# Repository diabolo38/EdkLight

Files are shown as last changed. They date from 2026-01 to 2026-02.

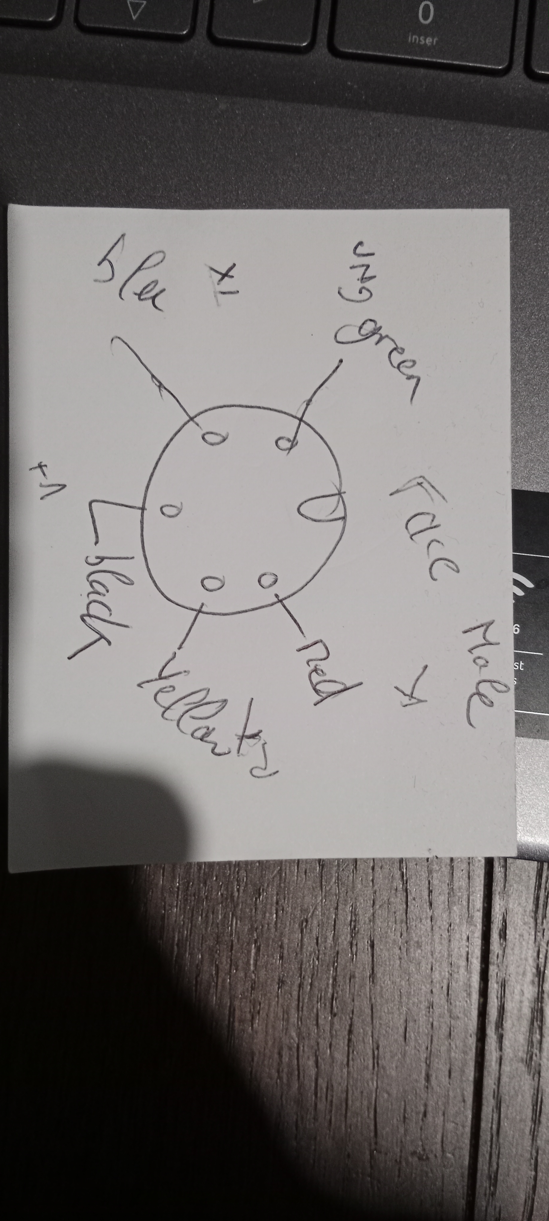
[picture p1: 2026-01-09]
doc/IMG_20260105_194908.jpg

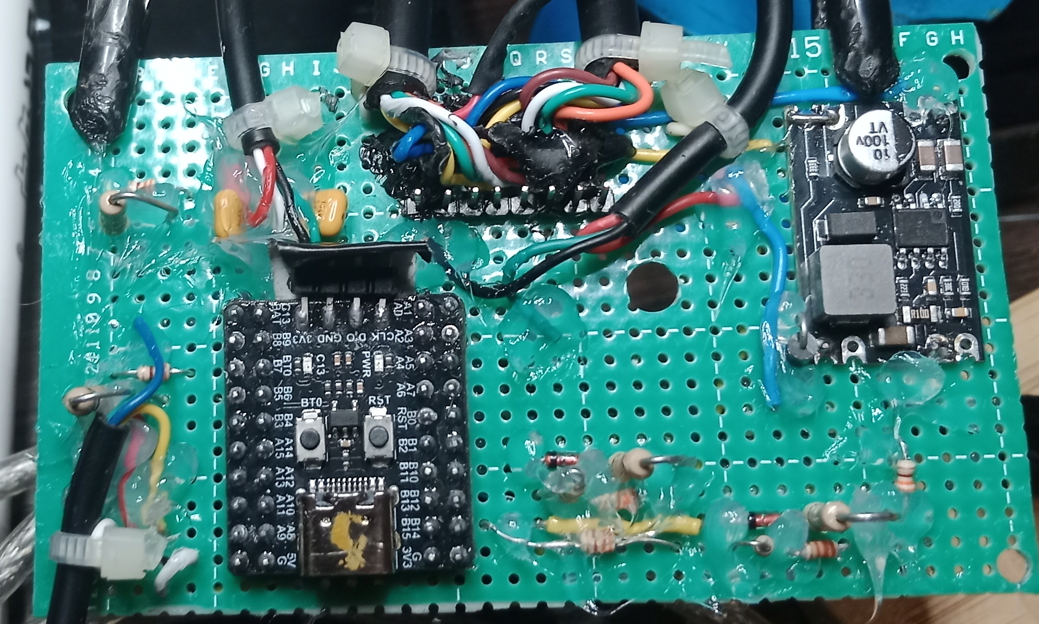
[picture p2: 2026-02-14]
doc/top.jpg

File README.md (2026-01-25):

Aim is to Drive my ebike light using the edk display light control via "+" key that is sent to motor via uart. 
optionaly brake light can be added  if conecting in at the higo 8 1 to 4 side.

An small mcu board stm32f103c6t6/c8t6  snif the edk-101  uart  and will enable power to light via  gpio base on control motor info snifed  
see https://github.com/hurzhurz/tsdz2/blob/master/serial-communication.md#motor-status-flags 

Hardware
---------
- Julet/Higo M8 5 pin Y spliter (light only) or Higo 8 extension for brake addition,  
- Julet 5 pin connector with 30cm wire take care that wires color don't seam to folow any standard (try conection and probe before to plug)
- 5V  step down  regulator with high enougth input voltage (54V + for 500W 48V TDS2B ) to feed 5V power from 48V bat line 
- MosFet  to drive  light pwoer (any mos capable to drive 500mA to 1A with  VDS max > 54V  ) 
- few discrete (zener, resistor)

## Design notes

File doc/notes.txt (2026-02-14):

ressource 
==========
wireless controler project for tsdz2 https://opensourceebike.github.io/easy_diy_display_ebike_display/tsdz2_wireless/ebike_wireless_controller.html 
schematic , cable pinout etc ....

connector 
========
Motor 4 to 1 source 
-------------------
higo 8 Pin (numbering from /ebike_wireless_controller) RX TX in motor sense 

    Brown/TX  8         2  Blue/Vbat
 Org/throt  7   1(GND)    3 Red/Vin(key)
Green/Brake   6         4 Yellow/RX
		           5 White/5V
		  color /pinout to be verified    GNB=black 
		  
 Check on mine (female view )
 1 black   GNB black ok
 2 blue    VBat
 3 red     Vin
 4 yellow  Rx  ok
 5 white   5V  ok
 6 Green   breake 
 7 Orang   Throt ok
 8 brown   Tx    ok
  all seamed ok as per number color but maping on function isn't ok 
		  
 functionaly it's not inline mine is 
 1 Gnd                            
 2 ? throt  analog 0 to 3.5V                             
 3 ? 4.3V  ? 5V 
 4 Rx 
 5 brake 
 6 TX  
 7 orange Vin                          
 8 brown VBat                                                         

Lcd/Motor 1 to 4 
--------
 Higo/Julet 5 pin M8 female , confirmed color as per my connector cable 
             (top Notch)
                   U     
  Gnd/Green     +    +  Key on /Red
Tx(RxLCD)/Blue  +    +  Rx(Tx lcd)/ Yellow
                  +
                 V+/Black (Bottom centered pin)

Ligth
------
front

https://fr.aliexpress.com/item/1005007666998243.html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

common ebike 36-80V led lamp with big front len
Max Powzer ~2.5W (50mA @ 54V)
 
3 lignes 
  rouge: ligne de corne / horn
  vert: ligne de lumière/ light
  noir: ligne commune  GND 
  
  Higo 3 pin cable extender female view front 
   
     Green  O   U    O Red  
          
                O Black

Rear 36/48V brake(flashing)+tail light 
   Red    ligh +
   black  ligh -
   
   Green Brake -
   Yellow Brake +

Higo 4 same color as light but black=blue 

 Red =>  lighjt + Vbat 
 black/blue = light -  on bot mos
 Green = brk - on bt mos 
 Yellow =brk + vbat
 
  female front view 
rouge L+   x  u  x green Brk - 
Yellow B+  x     x  Blue Light -

dual push buttton 
-------------------
Yellow 2x light (moded from auto locking to non locking) 
Blue  2x horn 

higo 4 
Red+black : light
white+green : horn 

  female front view 
  white  x  u  x Black
  Green  x     x  Red          
           bot 
mcu
=====
For dev proto the stm32f103 black pill low cost c6 or 8 (10K/20K sram)  
 https://stm32world.com/wiki/Black_Pill easier to wire 
 https://stm32-base.org/boards/STM32F103C8T6-Black-Pill.html
 https://hobbycomponents.com/st-micro-electronics/960-stm32f103-black-pill-development-board
The mini f103 10x2 he10 x2 more compact pcb aprox 2.54 x 2.54 cm vs 2.4 x 5.8 cm

Timers
-------- 
 # RX x1 x2 ?  idlle eof  time out  if to snif 2 Rx/Tx lcd/motor  => easy to avoid use last rx tick time in iddle loop to find eof
 # Rear Light PWM brake/full => this may not work if light has it's own dc/dc+ big enough cap unless pwm period quite low ( aka 100Hz range)
 # (opt? )  Rear blink time 
   
/!\ f103 has only 3 timer  + rtc => 4 h/w time source only out of 3 pwm capbale only 

UI
===

Brake : avoid keeping on/blink  , when keep pressed for too long and no move (aka press on red ligh)
when brake is on 
	if have speed or brake state chg : reset "keepOnDelay" ,  BrakeOverhide false
	else (no speed and no chg ) keepOnDelay elapsed check and set BrakeOverhide 

Light 
keep short to medium time presse for light on/off  
  if ligh presse => ligh on 
      after long press delay => setting mode 
   if ligh release before medium time => light state toogle (potneital on  
   if ligh release before long => set on 
   
  if displ light change => set the on state whatevr was the push button ligh status  

Power
------
EBike bat LiPo 13s 54.6V max, 48.1V nomimal 

5V Voltage regulator
-----------------
7-100V to 5V dc dc https://fr.aliexpress.com/item/1005005978350087.html?productId=1005005978350087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
may be usless if confimed a 5V on the 8 pin higo from wich we can take few 10mA 

Light control
--------------
IRFZ44N     vds max 55V  :( dangereous 
stp60nf06   vds max 60V  still close 10% margin vs max volt

smaller footprint I Max  ~ 1 to 2 Amp , Rdson ~0.1 ohm 
NTF2955   PMos sot 233 with 60V max but /!\ VGS max 20V => high side driving of light/horn 
NCE6005AR NMOS sot233  60V max 
BTS4140N 60V PMos sot223 hi side smart wicth with self protection  but rdson 1ohm :/
 BTS best more compact but power must be  limited (few 100mA 5 to  10W on 48V)

RX uart
======

9600 bps ~ 1ms/byte (8n1 => 10 bit per byte)

protol see https://github.com/hurzhurz/tsdz2/blob/master/serial-communication.md

Lcd to motor 
------------
Freq 15Hz  66.7ms period 
7 byte packet (~7ms time)
https://github.com/hurzhurz/tsdz2/blob/master/serial-communication.md#motor-status-flags

Rx idlle time out of 2ms shall be good eought , we rese cnt on  each byte rcv 
when timer end we can reset rx burst and stop timer until first of next burst 
=> best 2.5 to 3 byte idle tome aka 2.5 >3 ms 

PCB
==========

Blacpill pinout is wrong it's the f401 clsoe to bleu plill version not the f103 black pcb 
N/P mos used different  ref with same  SOT223 pinout

Acquired serial sequence on bike 
---------------------------------
Reverse confirmed information on spec+web but dit not find any direct "brake active" report usable to implemant read light control 

EDK sent PAS 1 light off 
name	type	start_time	duration	data
Async Serial	data	-0.00009808	0.00098944	0x59
Async Serial	data	0.000948	0.00098944	0x80
Async Serial	data	0.00199424	0.00098944	0x00
Async Serial	data	0.00304032	0.00098944	0x1A
Async Serial	data	0.00408656	0.00098944	0x00
Async Serial	data	0.00513264	0.00098944	0x3C
Async Serial	data	0.00617872	0.00098944	0x2F => sum 

PAS 1 ligh on 
name	type	start_time	duration	data
Async Serial	data	0.20295792	0.00098944	0x59
Async Serial	data	0.204004	0.00098944	0x81
Async Serial	data	0.20505008	0.00098944	0x00
Async Serial	data	0.20609632	0.00098944	0x1A
Async Serial	data	0.2071424	0.00098944	0x00
Async Serial	data	0.20818848	0.00098944	0x3C
Async Serial	data	0.20923472	0.00098944	0x30

PAS 2 Light On
name	type	start_time	duration	data
Async Serial	data	-0.00009808	0.00098944	0x59
Async Serial	data	0.000948	0.00098944	0x41 => bit 0 = light  bit 7 = PAS 1 bit 6 PAS 2 bit 5 pas 2 ….
Async Serial	data	0.00199424	0.00098944	0x00
Async Serial	data	0.00304032	0.00098944	0x1A
Async Serial	data	0.00408656	0.00098944	0x00
Async Serial	data	0.00513264	0.00098944	0x3C
Async Serial	data	0.00617872	0.00098944	0xF0

name	type	start_time	duration	data
Async Serial	data	-0.00009808	0.00098944	0x59
Async Serial	data	0.000948	0.00098944	0x09 = bit 4 = Pas 5  + bit 0 light ON 
Async Serial	data	0.00199408	0.00098944	0x00
Async Serial	data	0.00304032	0.00098944	0x1A
Async Serial	data	0.0040864	0.00098944	0x00
Async Serial	data	0.00513264	0.00098944	0x3C
Async Serial	data	0.00617872	0.00098944	0xB8
Async Serial	data	0.10144944	0.00098944	0x59
Async Serial	data	0.10249568	0.00098944	0x09
Async Serial	data	0.10354176	0.00098944	0x00
Async Serial	data	0.10458784	0.00098944	0x1A
Async Serial	data	0.10563408	0.00098944	0x00
Async Serial	data	0.10668016	0.00098944	0x3C
Async Serial	data	0.10772624	0.00098944	0xB8

=> confirm https://github.com/hurzhurz/tsdz2/blob/master/serial-communication.md#motor-control-flags is corret 

Motor PAS 5 light on  no move no break

name	type	start_time	duration	data
Async Serial [1]	data	0.01958704	0.00098944	0x43
Async Serial [1]	data	0.02073904	0.00098944	0x10
Async Serial [1]	data	0.02189088	0.00098944	0x00
Async Serial [1]	data	0.02304288	0.00098944	0x5C
Async Serial [1]	data	0.02419472	0.00098944	0x00
Async Serial [1]	data	0.02534672	0.00098944	0x00
Async Serial [1]	data	0.0264984	0.00098944	0x07
Async Serial [1]	data	0.0276504	0.00098944	0x07
Async Serial [1]	data	0.02880224	0.00098944	0xBD

Motor PAS 5 light on  no move + break
name	type	start_time	duration	data
Async Serial [1]	data	0.01043024	0.00098944	0x43
Async Serial [1]	data	0.01158272	0.00098944	0x10
Async Serial [1]	data	0.01273504	0.00098944	0x00
Async Serial [1]	data	0.01388736	0.00098944	0x5C
Async Serial [1]	data	0.01503952	0.00098944	0x00
Async Serial [1]	data	0.01619168	0.00098944	0x00
Async Serial [1]	data	0.01734384	0.00098944	0x07
Async Serial [1]	data	0.01849584	0.00098944	0x07
Async Serial [1]	data	0.01964784	0.00098944	0xBD

even when moving theirs no direct info on brake , 
status motor on and speed may give some brake hint but is not fully reliable

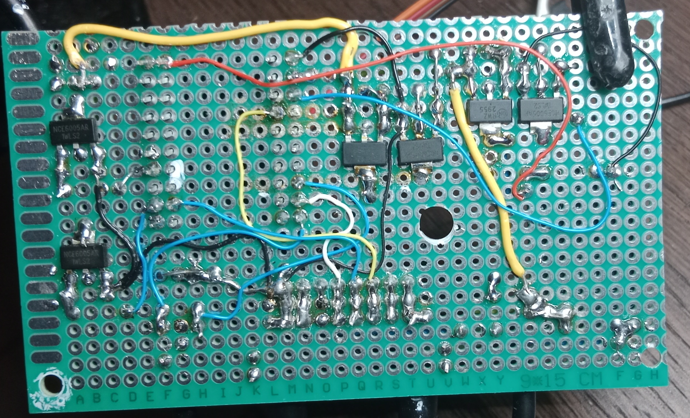
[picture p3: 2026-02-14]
doc/bottom.jpg

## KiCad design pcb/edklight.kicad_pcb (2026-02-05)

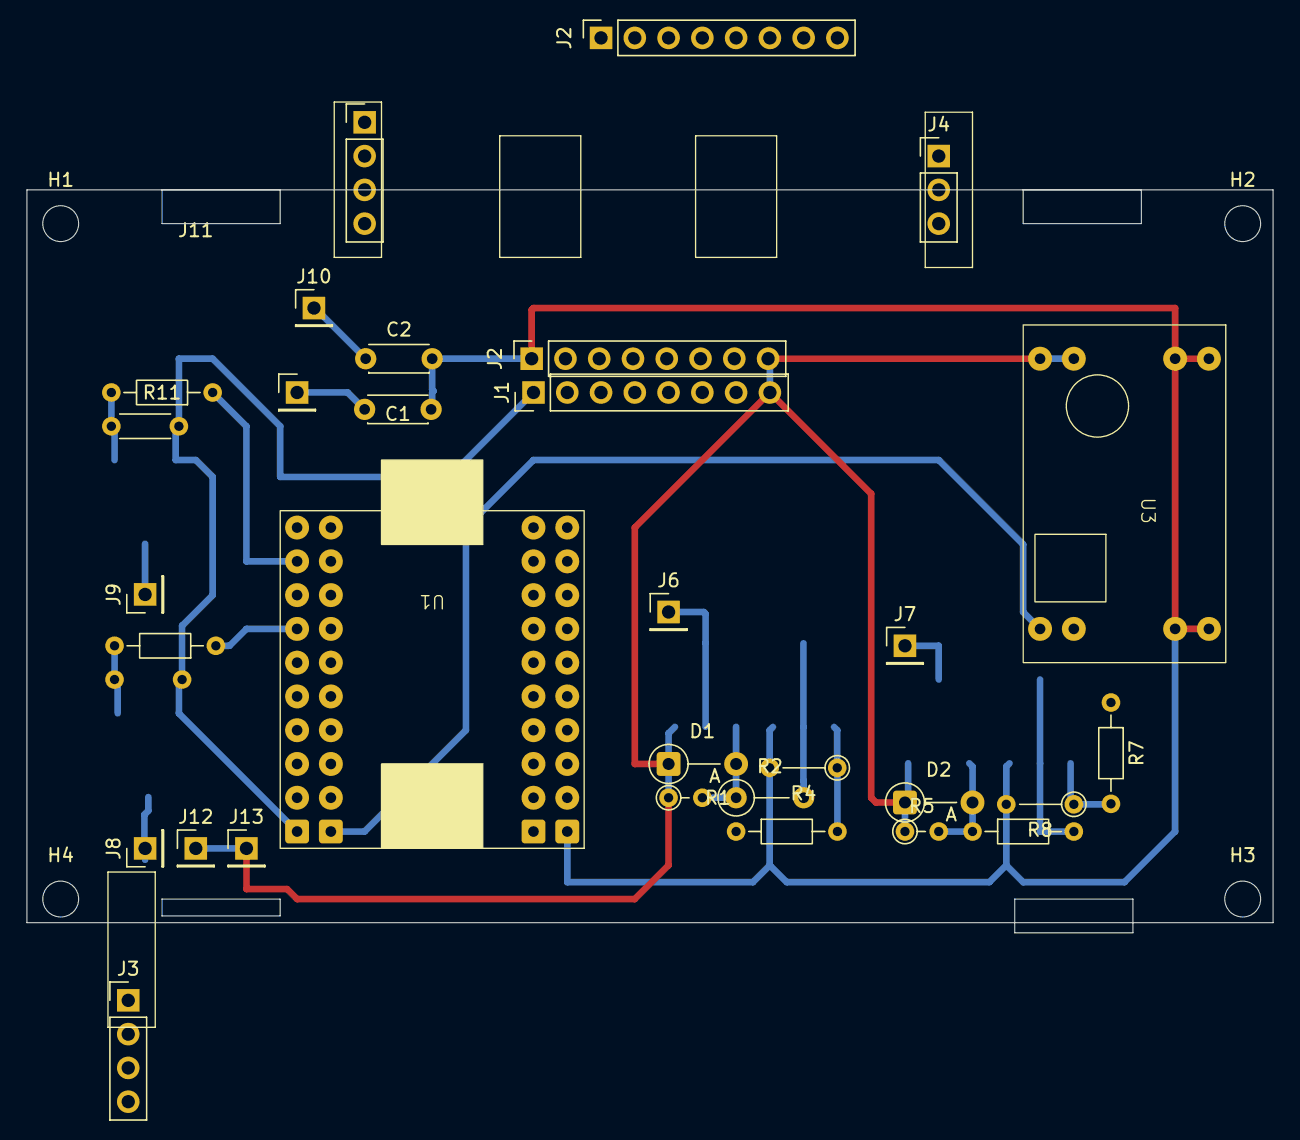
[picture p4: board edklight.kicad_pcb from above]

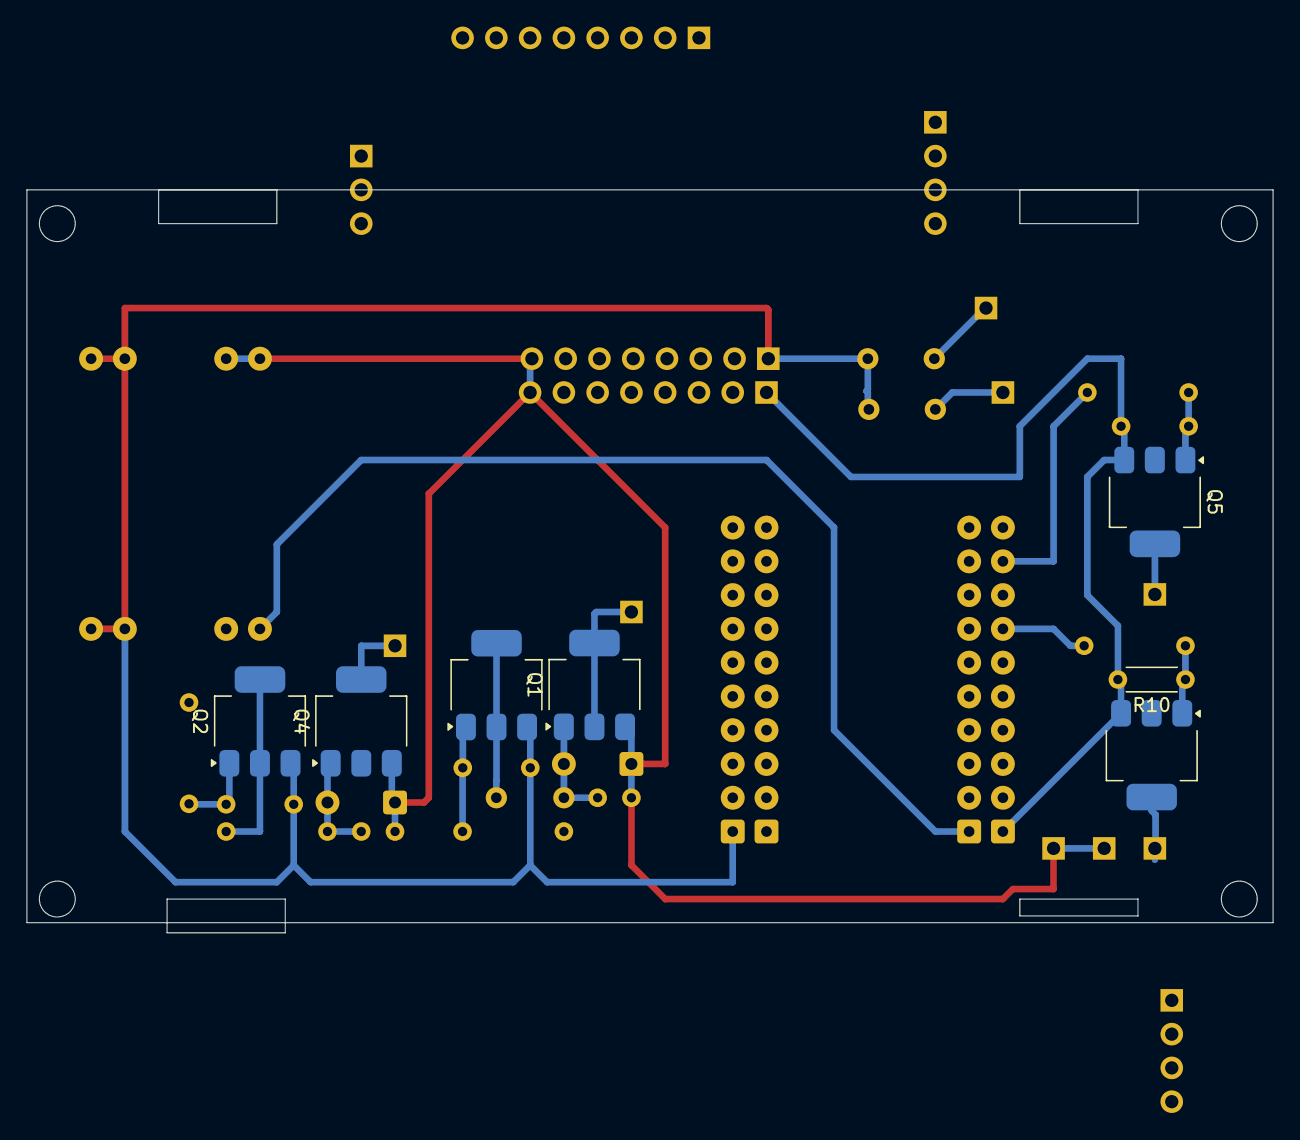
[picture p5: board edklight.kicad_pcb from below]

Board: 2 copper layers, 93.7 x 55.9 mm, 42 parts (7 on the bottom side), 27 nets.

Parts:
C1, C2: 100n; C_Disc_D4.3mm_W1.9mm_P5.00mm
D1, D2: 15V; D_A-405_P5.08mm_Vertical_AnodeUp
H1, H2, H3, H4: MountingHole; MountingHole_2.7mm_M2.5_DIN965
J1: MotorIn; PinHeader_1x08_P2.54mm_Vertical
J2, J2#2: ToLcd; PinSocket_1x08_P2.54mm_Vertical
J3: RearLight; PinHeader_1x04_P2.54mm_Vertical
J4: Fr Light; PinHeader_1x03_P2.54mm_Vertical
J5: 2 But Ctrl; PinHeader_1x04_P2.54mm_Vertical
J6, J7, J8, J9, J10, J11, J12, J13: Conn_01x01_Pin; PinHeader_1x01_P2.54mm_Vertical
Q1, Q4: ZXMP4A16G; SOT-223-3_TabPin2
Q2, Q3, Q5: nce6005; SOT-223-3_TabPin2
Q6: BSP89; SOT-223-3_TabPin2
R1, R5: 15K; R_Axial_DIN0204_L3.6mm_D1.6mm_P2.54mm_Vertical
R2: 33K; R_Axial_DIN0207_L6.3mm_D2.5mm_P5.08mm_Vertical
R3, R7, R9, R11: 330; R_Axial_DIN0204_L3.6mm_D1.6mm_P7.62mm_Horizontal
R4: 10K; R_Axial_DIN0204_L3.6mm_D1.6mm_P5.08mm_Vertical
R6: 33K; R_Axial_DIN0204_L3.6mm_D1.6mm_P7.62mm_Horizontal
R8: 10k; R_Axial_DIN0204_L3.6mm_D1.6mm_P5.08mm_Vertical
R10, R12: 10k; R_Axial_DIN0204_L3.6mm_D1.6mm_P5.08mm_Horizontal
U1: MiniF103
U3: dce003

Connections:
+5VD: U1.11 (5V), U3.7 (OUT+), U3.8 (OUT+)
BrakeIn: J1.5, J2#2.5, U1.19 (B9)
FLigh: J6.1, Q1.2 (D)
FLighOn: R3.1, U1.22 (B14)
GND: C1.2, C2.2, J1.1, J2#2.1, J5.1, J5.3, Q2.3 (S), Q3.3 (S), Q5.3 (S), Q6.3 (S), R4.2, R8.2, R10.2, R12.2, U1.1 (GND), U1.21 (GND), U3.1 (VIN-), U3.2 (VIN-), U3.5 (OUT-), U3.6 (OUT-)
Horn: J7.1, Q4.2 (D)
HornBut: C1.1, J5.2, J11.1, U1.28 (A5)
HornOn: R7.1, U1.23 (B12)
LighBut: C2.1, J5.4, J10.1, U1.30 (A1)
unnamed: D1.2 (A), Q1.1 (G), R1.2, R2.1
unnamed: D2.2 (A), Q4.1 (G), R5.2, R6.1
unnamed: J1.2, J2#2.2
unnamed: J1.3, J2#2.3
unnamed: J1.7, J2#2.7
unnamed: Q2.2 (D), R6.2
unnamed: Q2.1 (G), R7.2, R8.1
unnamed: Q3.2 (D), R2.2
unnamed: Q3.1 (G), R3.2, R4.1
unnamed: Q5.1 (G), R11.2, R12.1
unnamed: Q6.1 (G), R9.2, R10.1
RBrake: J8.1, Q6.2 (D)
RBrakeOn: R9.1, U1.7 (B5)
RLigh: J9.1, Q5.2 (D)
RLighOn: R11.1, U1.9 (B8)
RX: J1.4, J2#2.4, U1.29 (A3)
TX: J1.6, J2#2.6, U1.34 (B11)
VDD: D1.1 (K), D2.1 (K), J1.8, J2#2.8, J3.2, J3.4, J12.1, J13.1, Q1.3 (S), Q4.3 (S), R1.1, R5.1, U3.3 (VIN+), U3.4 (En)

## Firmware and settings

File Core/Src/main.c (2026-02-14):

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
/* Includes ------------------------------------------------------------------*/
#include "main.h"
#include "dma.h"
#include "tim.h"
#include "usart.h"
#include "gpio.h"

/* USER CODE BEGIN Includes */
#include <stdio.h>
#include <string.h>
#include <ctype.h>
/* USER CODE END Includes */

/* USER CODE BEGIN PM */
#define ARRAY_SIZE(x)  (sizeof(x)/sizeof(x[0]))
/* USER CODE END PM */


void SystemClock_Config(void);
/* USER CODE BEGIN PFP */
void Task_Ligth();
void MotDbg( char *str);

void SaveSetting();
/* USER CODE END PFP */

/* USER CODE BEGIN 0 */
#define SOFT_TIMEOUT	3 // ifdef use rx end of  message by soft time  time out else h/w timer used
//the 3  define the  time out in tick so between 2 and 3  ms given  1 ms error  on start and check
struct UartRcv_t {
	const char *Name; //human readable nick naleuse in log etc ..
	char RxByte; // recv byte
	volatile uint8_t nRx;   // Data cnt in Rx Buf
	uint8_t RxMax; // Size of burst

	char HdrByte; // first byte expected value

	int RxBufSz;
	char RxBuf[16]; //

	int nErr;
	volatile int TimedOut;
	uint32_t LastRcvGood; // tick last full msg received
	uint32_t LastRxTick; // last char received tick for soft time out handling
	uint32_t BadRx;
	UART_HandleTypeDef *huart;
	TIM_HandleTypeDef  *htim;
	void  (*Process)(struct UartRcv_t *Rx); //call when burst data received
};

// led set ticking in idle with low/high leelv state  fm light status => don' give info on live rx+f/w status
// Led set by process and then  toggle once by idle after short time is better
//   led blink until rx is ok ,if not bug f/W stuck ?
//   "static" led level high/low is the light sniffed level
volatile int light_upd; // flags set when edk reception done (potential light,speed  change )
volatile int LightOn=0; // set by com of edk+man when chanign one call SetLighON if nto then udpate wil loccur and net light task
volatile int EdkLightOn=0; // set by process to sniffed light  value
volatile int ManLightOn=0; // set by process to sniffed light  value
int LightOn_p=1; //task previous light level used (chg detection)
int OnLvl_p=0;   // previous ser ligh level
int HiBeam, HiBeam_p;
int FlightPwm = 0; //may init by ee or chg by button combo
uint32_t LedSetTick;
struct GlobStatus_t gStats;
//todo below make init value from nvm
volatile int OnLvl=512;

#define MinLongPressMs 1000  //ee read clip value

//motor
int MotRcvCnt=0;
char MotInfo[64];
int MotSpeed;
const int SpeedInvalid=0x7777; //until more than  noNove shall do
const int SpeedNoMove=0x0707;
int MotNoRxMaxMs = 1000; //normaly 15fps so 500ms+  well set invaldi speed
int MotTorque;
uint8_t MotStatus;


void DbgIO(int set){
	if( set ==0 || set ==1 )
		HAL_GPIO_WritePin(DBG_IO_GPIO_Port, DBG_IO_Pin, set);
	else
		HAL_GPIO_TogglePin(DBG_IO_GPIO_Port, DBG_IO_Pin);
}

void DbgIO2(int set){
	if( set ==0 || set ==1 )
		HAL_GPIO_WritePin(DBG2_GPIO_Port, DBG2_Pin, set);
	else
		HAL_GPIO_TogglePin(DBG2_GPIO_Port, DBG2_Pin);
}


uint32_t SumSerie(uint8_t *Data, int n){
	uint32_t sum;
	int i;
	for( i=0, sum=0; i<n; i++)
		sum+=Data[i];
	return sum;
}

//Rx shall have at least RaMax data this is not check here
/**
 * VAldiate buffer start byet and sum
 * Rx shall have at least RaMax data this is not check here
 * @param Rx The ex
 * @return 0 f validate non 0 otherwise
 */
int RxValidate(struct UartRcv_t *Rx) {
	uint32_t sum;
	if (Rx->RxBuf[0] == Rx->HdrByte ) {
		sum = SumSerie((uint8_t*) Rx->RxBuf, Rx->RxMax-1);
		if ( (sum & 0xFF) == Rx->RxBuf[Rx->RxMax - 1]) {
			return 0;//ok packet is valid
		}
	}
	return -1;
}


void  EdkProcess(struct UartRcv_t *Rx){
	if( RxValidate(Rx)==0 ){
		Rx->LastRcvGood = HAL_GetTick();
		EdkLightOn =Rx->RxBuf[1]&0x01; // bit 0 of control motor flags
		light_upd=1;
	}else {
		Rx->BadRx++;// shit rx 1 byte ?
	}
}



//from https://github.com/PetteriAimonen/STM32_Trace_Example/blob/master/trace_example.c
void ITM_Print(int port, const char *p)
{
    if ((ITM->TCR & ITM_TCR_ITMENA_Msk) && (ITM->TER & (1UL << port)))
    {
        while (*p)
        {
            while (ITM->PORT[port].u32 == 0);
            ITM->PORT[port].u8 = *p++;
        }
    }
}

void configure_tracing()
{
    /* STM32 specific configuration to enable the TRACESWO IO pin */
    RCC->APB2ENR |= RCC_APB2ENR_AFIOEN;
    AFIO->MAPR |= (2 << 24); // Disable JTAG to release TRACESWO
    DBGMCU->CR |= DBGMCU_CR_TRACE_IOEN; // Enable IO trace pins

    if (!(DBGMCU->CR & DBGMCU_CR_TRACE_IOEN))
    {
        // Some (all?) STM32s don't allow writes to DBGMCU register until
        // C_DEBUGEN in CoreDebug->DHCSR is set. This cannot be set by the
        // CPU itself, so in practice you need to connect to the CPU with
        // a debugger once before resetting it.
        return;
    }

    /* Configure Trace Port Interface Unit */
    CoreDebug->DEMCR |= CoreDebug_DEMCR_TRCENA_Msk; // Enable access to registers
    TPI->ACPR = 0; // Trace clock = HCLK/(x+1) = 8MHz = UART 's baudrate
                   // The HCLK of F105 is 8MHz so x is 0, and the F103 is 72MHz so x is 8
    TPI->SPPR = 2; // Pin protocol = NRZ/USART
    TPI->FFCR = 0x102; // TPIU packet framing enabled when bit 2 is set.
                       // You can use 0x100 if you only need DWT/ITM and not ETM.

    /* Configure PC sampling and exception trace  */
    DWT->CTRL = (1 << DWT_CTRL_CYCTAP_Pos) // Prescaler for PC sampling
                                           // 0 = x64, 1 = x1024
              | (0 << DWT_CTRL_POSTPRESET_Pos) // Postscaler for PC sampling
                                                // Divider = value + 1
              | (1 << DWT_CTRL_PCSAMPLENA_Pos) // Enable PC sampling
              | (2 << DWT_CTRL_SYNCTAP_Pos)    // Sync packet interval
                                               // 0 = Off, 1 = Every 2^23 cycles,
                                               // 2 = Every 2^25, 3 = Every 2^27
              | (1 << DWT_CTRL_EXCTRCENA_Pos)  // Enable exception trace
              | (1 << DWT_CTRL_CYCCNTENA_Pos); // Enable cycle counter

    /* Configure instrumentation trace macroblock */
    ITM->LAR = 0xC5ACCE55;
    ITM->TCR = (1 << ITM_TCR_TraceBusID_Pos) // Trace bus ID for TPIU
             | (1 << ITM_TCR_DWTENA_Pos) // Enable events from DWT
             | (1 << ITM_TCR_SYNCENA_Pos) // Enable sync packets
             | (1 << ITM_TCR_ITMENA_Pos); // Main enable for ITM
    ITM->TER = 0xFFFFFFFF; // Enable all stimulus ports

    /* Configure embedded trace macroblock */

}


void  MotProcess(struct UartRcv_t *Rx){
	if( RxValidate(Rx)==0 ){
		Rx->LastRcvGood = HAL_GetTick();

		MotStatus=Rx->RxBuf[2];
		if(Rx->RxBuf[4]> Rx->RxBuf[3])
			MotTorque=Rx->RxBuf[4]-Rx->RxBuf[3]; //only if 4 > 3 or motot on else vive negative number or status say mot on
		else
			MotTorque=0;
		MotSpeed=Rx->RxBuf[7]+((uint32_t)Rx->RxBuf[7]<<8); // max 0x0707 / 1799 when stoped of very slow
		//once every sec trace
		if( MotRcvCnt++ > 15){
			sprintf(MotInfo,"St %02X S %d C %d",MotStatus, MotSpeed, MotTorque );
			MotDbg(MotInfo);
			//ITM_Print(0, MotInfo);
			MotRcvCnt=0;
		}
	}else {
		// shit rx 1 byte ?
		Rx->BadRx++;
	}
}

/**USART1 GPIO Configuration
   PA9     ------> USART1_TX
   PA10     ------> USART1_RX to usb
   */

struct UartRcv_t   EdkRx = {
		.Name ="Edk",
		.RxMax = 7, // edk sent 7 byte per packet
		.HdrByte = 0x59,
		.RxBufSz = sizeof(EdkRx.RxBuf),
		.huart = &huart2,
		/**USART2 GPIO Configuration
		PA2     ------> USART2_TX
		PA3     ------> USART2_RX
		*/
		.htim = &htim2,
		.Process = EdkProcess,
};

struct UartRcv_t   MotRx = {
		.Name ="Mot",
		.RxMax = 9, // tsdz2b sent 8 byte per packet
		.HdrByte = 0x43,
		.RxBufSz = sizeof(MotRx.RxBuf),
		.huart = &huart3,
		/**USART3 GPIO Configuration
		  PB10     ------> USART3_TX
		  PB11     ------> USART3_RX
		  */
		.Process = MotProcess,
};


struct UartRcv_t UsbRx = {
	.Name ="Usb",
	.RxMax =  sizeof(UsbRx.RxBuf) -1 , // keep one to add 0 en f=to use string function
	.RxBufSz = sizeof(UsbRx.RxBuf),
	.huart = &huart1,
	// no process not header
};

void KickRx(struct UartRcv_t *Rx){
	Rx->nRx=0;
#ifdef SOFT_TIMEOUT
	Rx->LastRxTick= HAL_GetTick();
#else
	__HAL_TIM_DISABLE(Rx->htim);
#endif
	HAL_UART_Receive_IT(Rx->huart, (void*)Rx->RxBuf,1);
}

void Rcv_ReamTimeOut(struct UartRcv_t *Rx){
#ifdef SOFT_TIMEOUT
	Rx->LastRxTick = HAL_GetTick();
#else
	if( RxRx->htim != NULL ){
		Rx->htim->Instance->CNT=0;
		__HAL_TIM_CLEAR_FLAG(Rx->htim, TIM_FLAG_UPDATE);
		__HAL_TIM_ENABLE_IT(Rx->htim, TIM_IT_UPDATE);
		__HAL_TIM_ENABLE(Rx->htim);
		DbgIO(-1);
	}else
		Rx->LastRxTick = HAL_GetTick();
#endif
}

void HAL_UART_RxCpltCallback(UART_HandleTypeDef *huart){
	struct UartRcv_t  *Rx = huart == EdkRx.huart ? &EdkRx : huart == MotRx.huart  ? &MotRx : &UsbRx;
	if(Rx->nRx < Rx->RxBufSz ){
		Rx->RxBuf[Rx->nRx]=Rx->RxByte;
		Rx->nRx++;
	}
	else {
		//how can ? idle is dead not picking ?
	}
	HAL_UART_Receive_IT(Rx->huart, (void*)&Rx->RxByte,1);

	if( Rx->nRx < Rx->RxMax ) // when full packet received no need to use idle time for end of burst detection
		Rcv_ReamTimeOut(Rx);  // save cpu time and minimize race timer isr/idle rx check
}

void HAL_UART_TxCpltCallback(UART_HandleTypeDef *huart){
	if( huart == UsbRx.huart){
		LogTxComplete();
	}
}
void HAL_UART_ErrorCallback(UART_HandleTypeDef *huart){
	struct UartRcv_t  *Rx = huart == EdkRx.huart ? &EdkRx : huart == MotRx.huart  ? &MotRx : &UsbRx;
	Rx->nErr++;
	//Rx->nRx = 0;
	//We could continue on the end crc +  timeout with not enough data  will says if good anyway
	//  if error is due to some glitch extra rcv , it can  be good on the end
	HAL_UART_Receive_IT(Rx->huart, (void*)&Rx->RxByte,1);
	Rcv_ReamTimeOut(Rx);
}

void HAL_TIM_PeriodElapsedCallback(TIM_HandleTypeDef *htim){
	struct UartRcv_t  *Rx = htim == EdkRx.htim ? &EdkRx : &MotRx;
	__HAL_TIM_DISABLE_IT(Rx->htim, TIM_IT_UPDATE);
	__HAL_TIM_DISABLE(htim);
	DbgIO(-1);
	htim->Instance->CNT = 0 ;
	Rx->TimedOut = 1;
}

/**
 * reset reception
 */
void RxReset( struct UartRcv_t  *Rx){
	 Rx->nRx = 0 ;
	 Rx->TimedOut = 0;
#ifdef SOFT_TIMEOUT
	 Rx->LastRxTick = HAL_GetTick();
#endif
}

void LedCheck(){
	if( HAL_GetTick() - LedSetTick > 250 ){
		LedSetTick = HAL_GetTick();
		HAL_GPIO_TogglePin(LED_GPIO_Port, LED_Pin);
	}
}

#define inrange( x , min , max ) ( ((x)>= (min)) && ((x)<=(max)) )
#define MIN(a,b) ((a)<(b) ? (a):(b))

int SetupStayMS=1000; //time/Speed each ligh level stay before next
struct Setup_t {
	unsigned SetupActiv : 1;
	uint8_t RepCnt;
	uint16_t CurLvl;
	uint32_t StepStartTick;
}Setup;

enum ButState_e {
	BStWaitPress=0,
	BStLongWait = 1,
	BStLongDone = 2 , // wait long done action now wait release or else
};

void LbutSetup(){
	Log("Setup\n");
	if( LightOn ){ // enable on light on only  still possibel w/o mcd/moto via button on first
		if( Setup.SetupActiv == 0 ){
			Setup.SetupActiv = 1;
			Setup.RepCnt = 0;
			Setup.StepStartTick = HAL_GetTick();
			Setup.CurLvl = OnLvl;
		}
	}
}

void SetLighOn(){
	LightOn=EdkLightOn|ManLightOn;
}

void Lbut_EventCb(int event){
	switch( event ){
	case Lbut_EvShort :
		HiBeam= !HiBeam;
	break;
	case Lbut_EvLong :
		ManLightOn = ! ManLightOn;
		SetLighOn();
	break;
	}
}
/**
 *
 * @param lvl 0..1024
 */
void Light_SetLvl(int lvl){
	htim1.Instance->CCR2 = lvl; //OnLvl 1 pulse low all over hight 1025 (arr+1) for full on
}
//Call only if activ
int  SetupLvl(uint32_t now) {
	if (now - Setup.StepStartTick > SetupStayMS) {
		Setup.CurLvl += 1024 / 8;
		if (Setup.CurLvl > 1024+127 ) { //We want a case 100%
			if (Setup.RepCnt++ > 3) {
				Setup.SetupActiv =0;
				Log("Setup cancel\n");
				return OnLvl;
			}
			Setup.CurLvl = 128;
		}
		Setup.StepStartTick = now;
		Log("Setup %d\n",Setup.CurLvl);
	}

	return  Setup.CurLvl; //full on when but pressed unless some pause
}

void ChgLevel(){
	Setup.SetupActiv = 0;
	Log("Setup chg %d => %d\n", OnLvl, Setup.CurLvl);
	OnLvl = Setup.CurLvl == 1024 ? 1025 :  Setup.CurLvl  ; //the loop roll at 1024 but we want dc full on not 999.9%  pwm
	SaveSetting();
}

void Task_Ligth(){
	uint32_t now;
	int ButChg;

	uint8_t ButLvl =  HAL_GPIO_ReadPin(BUT_LIGHT_GPIO_Port, BUT_LIGHT_Pin);
	now = HAL_GetTick();
	ButChg = task_Lbut( now, ButLvl);

	if( ButChg && Setup.SetupActiv  ){ //not that setup is entered after reste tiemof button after 3+2 pulse
		ChgLevel(); //capture current level when change while setup active (do not wait release)
	}
	SetLighOn();


	if( LightOn != LightOn_p ||OnLvl != OnLvl_p || ButChg || Setup.SetupActiv || HiBeam != HiBeam_p){
		int IsOn, OnLv;
		LightOn_p = LightOn;
		OnLvl_p = OnLvl;
		HiBeam_p = HiBeam;

		IsOn = LightOn || ButLvl==0; //When pressed force high/on
		//When pulse press and on we shall set off few msec to emphasis light pulse
		//WHen main light is short pulse may be used to toogle hgh/lwo beam hih/low
		if( FlightPwm ){
			if( Setup.SetupActiv ){
				OnLv = SetupLvl(now);
			}
			else{

				OnLv = ButLvl ==0 || HiBeam ?  1025 : OnLvl; //full on when but pressed or high  unless some pause ? or hih/low
			}
			Light_SetLvl(IsOn || Setup.SetupActiv  ? OnLv  : 0);
			//We repeat Setup.SetupActiv as it may got off but even we wan't would be ok
		}
		else {
			HAL_GPIO_WritePin(FLIGHT_PWM_GPIO_Port,FLIGHT_PWM_Pin, IsOn);
		}
		HAL_GPIO_WritePin(RLIGHT_ON_GPIO_Port, RLIGHT_ON_Pin, LightOn); // real ligh no pww not chg on flash by button
	}
	//rear light is  on until display say on
	HAL_GPIO_WritePin(RLIGHT_ON_GPIO_Port, RLIGHT_ON_Pin, LightOn );

}

struct BrakeeData_t {
	unsigned  state :1;
	unsigned  stoped:1;
	unsigned  Active :1;
	uint32_t LastChg;
	uint32_t StropedStart;
}Brake;

int BrakeDebounceMs = 2;
int BrakeOffTimeMS = 4000; // afster 4s speed 0 and brake press stop teh brake lihj

void MotMakeLost(){
	MotSpeed = SpeedInvalid;
}
//does the mot lost too
void Task_Brake(){
	uint32_t now;
	int BrakeHide = 0;
	now = HAL_GetTick();
	if( now - MotRx.LastRcvGood > MotNoRxMaxMs){
		//Assume lost com or off
		MotMakeLost();
	}
	int BrakeIn = HAL_GPIO_ReadPin(BRAKE_IN_GPIO_Port, BRAKE_IN_Pin);
	if( Brake.state != BrakeIn ){
		Brake.LastChg= now;
		Brake.state = BrakeIn;
	}
//	if( now - Brake.LastChg < BrakeDebounceMs ){
//		return;
//	}
	BrakeHide = 0; //Don't hide default
	if(BrakeIn == 0 ){ // active
		if( MotSpeed == SpeedNoMove ){
			if( Brake.stoped == 0  ){
				Brake.stoped =1;  // stop first seen
				Brake.StropedStart = now;//Start counting tile
			}
			else { // keep stoped check time for hiding stoping brake light
				BrakeHide = now - Brake.StropedStart > BrakeOffTimeMS;
			}
		}
		else {
			Brake.stoped = 0; //move hence not stoped
		}
	}
	else {
		Brake.stoped = 0;
	}
	Brake.Active = (BrakeIn==0) && (! BrakeHide)  ;
	HAL_GPIO_WritePin(BRAKE_ON_GPIO_Port, BRAKE_ON_Pin, Brake.Active);
}

void Task_Horn(){
	int HornIn = HAL_GPIO_ReadPin(BUT_HORN_GPIO_Port, BUT_HORN_Pin);
	HAL_GPIO_WritePin(HORN_ON_GPIO_Port, HORN_ON_Pin, !HornIn); // io  is pull-up with button short to gnd
}

// test sequence we send to ourself
static uint8_t Pas1_Ligh0[] ={ 0x59, 0x80, 0x00, 0x1A, 0x00, 0x3C, 0x2F }; //EDK sent PAS 1 light off
static uint8_t Pas2_Ligh1[] ={ 0x59, 0x41, 0x00, 0x1A, 0x00, 0x3C, 0xF0 }; //EDK sent PAS 12 light on
uint8_t *DbgTx= Pas2_Ligh1; //change during debug session  to one  above array or data to send ptr

/**
 * send actual DbgTx data array on Mot Tx (externaly  wired to Edk Rx for dev and debug)
 * @param Cnt [in/out] byte count to send ,  cleared at output
 */
void DoDbgTx(int *Cnt){
	if( Cnt && MotRx.huart->gState ==  HAL_UART_STATE_READY ){
		HAL_UART_Transmit_DMA(MotRx.huart, DbgTx,*Cnt);
		*Cnt= 0;
	}
}
//for debug We send motor just recived info on edk tx once evey n
void MotDbg( char *str){
	int n;
	if ( EdkRx.huart->gState ==  HAL_UART_STATE_READY ){
		n=strlen(str);
		HAL_UART_Transmit_DMA(EdkRx.huart, (void*)str, n);
	}
}


//  state     cond/event -> next {action}; * rep cond act ...
// rest state = high (pull up ) button short capacitor to gnd
//  Idle      :   lowEdge -> SHortWait {SetLigh(full) , TimeEdge=now} ;
//  ShortWait :  HighEdge -> Idle {LightOff, if time fm last short < tdbl -> dbl click ()} ;
//               TFromEdge > Long  -> LongWait { SetLigh(lvl) }
// LongWait   :  HighEdge ->Idle { Store new lvl if chg}

// short  from ligh off et on stop on release "short beam warn"
// short when on => nothing of set lvl max , short off befoe one "high beam warm"
// long turn on/off as time > no action on release
// very long  ? => enter  lvl setting level  increase level rotating in aprox  1 sec step and set new lev on release

void InitLight(){
	// tim1 ch2n
	FlightPwm=1; //get from ee
	htim1.Instance->CCR1 = 0; //Set off default before first  update done
	HAL_TIM_PWM_Start(&htim1, TIM_CHANNEL_1);
	HAL_TIMEx_PWMN_Start(&htim1, TIM_CHANNEL_2);
	Light_SetLvl(0);
}

struct UCmd_t {
	const char * cmd ;
	const char * help;
	int len;
	void (*validate)(struct UCmd_t *, char*);
};

int CmdL;
#define IsBlank(x) (x==' ' || x == '\t' || x == '\r' || x == '\n')
void ValidateLight(struct UCmd_t *cmd, char *str){
	int v,n;
	if( !IsBlank(str[cmd->len]) ){
		//we need white space and then only value
		return;
	}
	n = sscanf(str+cmd->len ,"%d", &v);
	if( n < 1)
		return ;

	if( v<0 ){
		v =0;
	}
	else if ( v>= 100 ){
		v= 100;
	}
	OnLvl = v*1024/100;
	Log("Lvl set %d %d%%",OnLvl, v );
}

void CmdStat(struct UCmd_t *cmd, char *str);
void CmdConf(struct UCmd_t *cmd, char *str);
void CmdErase(struct UCmd_t *cmd, char *str);

struct UCmd_t Cmds[]= {
		/*warning parser is over simple not too command can start the same or if they do
		 * the longest one must be place first so longest match/cmp  is done first
		 *
		 */
		{ .cmd = "lvl", .validate = ValidateLight , .help="% d 0-100 %% pwm"},
		{ .cmd = "stat", .validate = CmdStat , .help="do log status"},
		{ .cmd = "conf", .validate = CmdConf , .help="show config"},
		{ .cmd = "erase", .validate = CmdErase , .help="Erase ee (def config)"},
};

struct UsbTask_t {
	int LastNRx; //to detect  new char arrival on usb rx
	uint32_t StatusErr;
}UsbTh;

void DoHelp(){
	Log("\n?\n");
}

struct UartRcv_t *RxLut[] = {
		&EdkRx,
		&MotRx,
		&UsbRx
};

int UsbRxWaitTxrdy(int MsMax){
	uint32_t t0 = HAL_GetTick();
	do {
		if ( UsbRx.huart->gState ==  HAL_UART_STATE_READY ){
				return 0;
		}
	}while(HAL_GetTick() - t0 < MsMax);
	return -1;
}


void LogConf(){
	Log("Conf : Lvl %d %d%% L Press %ds\n", OnLvl, OnLvl*100/1024, LongPressMs/1000);
}

void DoStatus(){
	int i;
	struct UartRcv_t *Rx;
	Log("Now %u\n", (unsigned)HAL_GetTick());
	for( i=0 ; i < ARRAY_SIZE(RxLut); i++ ){
		Rx=RxLut[i];
		Log("%s\nBadRX %u Err %u\n", Rx->Name, (unsigned)Rx->BadRx, (unsigned)Rx->nErr);
		Log("Lg %u Lrx %u\n", (unsigned)Rx->LastRcvGood, (unsigned)Rx->LastRxTick);
	}
	Log("Th stat err %u\n", (unsigned)UsbTh.StatusErr);
	Log("Log empty %d Wrap %d Drop %d Wait %d\n ",
			Stats(EmptyLog), Stats(WrapLog), Stats(DropLog),Stats(WaitLog));
	LogConf();
}

void SaveSetting(){
	struct EeData_t Set={0};
	Set.FrontLevel = 100*OnLvl/1024;
	Set.LongPressSec = LongPressMs / 1000;
	EeSetEntry(&Set);
}

void SetConfFromEe(const struct EeData_t *Activ){
	OnLvl = Activ->FrontLevel* 1024/100;
	LongPressMs = Activ->LongPressSec*1000;
	LongPressMs = LongPressMs < MinLongPressMs ? MinLongPressMs : LongPressMs; // as 0 may lead to strnage behavior clip some value

}
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
int main(void)
{

  /* USER CODE BEGIN 1 */
	  struct UartRcv_t  *Rx;
	  int i;
	  volatile int DbgTxCnt=0;
	  volatile int RepDbg=0;
	  int TickNext=0;
	  volatile int trace_en=0; /// for dynamaic when dbg attach to enable trace
	  volatile int trace_test=0;
  /* USER CODE END 1 */

  /* MCU Configuration--------------------------------------------------------*/

  /* Reset of all peripherals, Initializes the Flash interface and the Systick. */
  HAL_Init();

  /* Configure the system clock */
  SystemClock_Config();

  /* USER CODE BEGIN SysInit */
  DbgTx= RepDbg ? Pas2_Ligh1 : Pas1_Ligh0; //Trick to avoid  data removed at link cos unused
  /* USER CODE END SysInit */

  /* Initialize all configured peripherals */
  MX_GPIO_Init();
  MX_DMA_Init();
  MX_USART1_UART_Init();
  MX_USART2_UART_Init();
  MX_TIM2_Init();
  MX_TIM3_Init();
  MX_TIM1_Init();
  MX_USART3_UART_Init();
  /* USER CODE BEGIN 2 */
  //configure_tracing();
  //DoLog("Boot");
  //ee_check();
  InitConf();
  UCmdInit();
  InitLight();
  Task_Ligth(); // init prev
  KickRx(&EdkRx);
  KickRx(&MotRx);
  KickRx(&UsbRx);

  /* USER CODE END 2 */

  /* Infinite loop */
  /* USER CODE BEGIN WHILE */
  while (1)
  {
  	  //Check for 2 Rx time out out Rx limit
	  for( i=0; i<2; i ++ ) { //dbgg only run the displauy rx
		 Rx = i==0 ? &EdkRx : &MotRx;

		 if ( Rx->nRx >=  Rx->RxMax ){
			 if(Rx->Process )
					Rx->Process(Rx);
			 RxReset(Rx);
			 //When process/validate is bad shift data out rather than reset any better ?
			 // this can cope with case we had data from prev or junk + current packet still  entering
			 // this shall not occur with no rx time out detection any partial packet is droped.

		 }else {
#ifdef SOFT_TIMEOUT
			 if( Rx->nRx > 0){ //no time handlign until rcv anything
				 Rx->TimedOut = HAL_GetTick()  - Rx->LastRxTick > SOFT_TIMEOUT;
			 }
#endif
			 if( Rx->TimedOut && Rx->nRx < Rx->RxMax ){ // repeat check minimize unlikely race effect
				 RxReset(Rx);
			 }
		 }
	  }
	  //todo handle usb rx
	  UCmdCheck();
	  if( DbgTxCnt || RepDbg ){
		  // do debug tx
		  if( RepDbg && HAL_GetTick() > TickNext ) {
			  DbgTxCnt=7;
			  RepDbg--;
			  TickNext = HAL_GetTick()+ 66; //66  ms 15Hz as lcd rate
			  DoDbgTx((void*)&DbgTxCnt);
		  }
	  }
	  Task_Brake();
	  LedCheck();
	  Task_Ligth();
	  Task_Horn();
	  if( trace_en){
		  configure_tracing();
		  trace_en = 0;
	  }
	  if( trace_test){
		  sprintf(MotInfo, "Test %d", (int)HAL_GetTick());
		  ITM_Print(0,MotInfo);
		  trace_test=0;
	  }
    /* USER CODE END WHILE */

    /* USER CODE BEGIN 3 */
  }
  /* USER CODE END 3 */
}

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


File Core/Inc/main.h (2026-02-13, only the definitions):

#define EE_CTRL_VALID	0xA5
#define EE_CTRL_DEL		0x00
#define LED_Pin GPIO_PIN_13
#define LED_GPIO_Port GPIOC
#define BUT_LIGHT_Pin GPIO_PIN_1
#define BUT_LIGHT_GPIO_Port GPIOA
#define BUT_LIGHT_EXTI_IRQn EXTI1_IRQn
#define BUT_HORN_Pin GPIO_PIN_5
#define BUT_HORN_GPIO_Port GPIOA
#define BUT_HORN_EXTI_IRQn EXTI9_5_IRQn
#define DBG2_Pin GPIO_PIN_1
#define DBG2_GPIO_Port GPIOB
#define HORN_ON_Pin GPIO_PIN_12
#define HORN_ON_GPIO_Port GPIOB
#define DBG_IO_Pin GPIO_PIN_13
#define DBG_IO_GPIO_Port GPIOB
#define FLIGHT_PWM_Pin GPIO_PIN_14
#define FLIGHT_PWM_GPIO_Port GPIOB
#define BRAKE_ON_Pin GPIO_PIN_5
#define BRAKE_ON_GPIO_Port GPIOB
#define RLIGHT_ON_Pin GPIO_PIN_8
#define RLIGHT_ON_GPIO_Port GPIOB
#define BRAKE_IN_Pin GPIO_PIN_9
#define BRAKE_IN_GPIO_Port GPIOB

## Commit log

2026-01-09 rx tx dbg in progress to regn with correct usart bps
    [EdkLight.ioc, main.c]
2026-01-09 regen mcu clk to low , debug time out
    likely mcu to slow causing timer/uart races bad behavior
    is now ok 2ms time out maye a bit short 3 ms woumd be better
    [EdkLight.ioc, main.c]
2026-01-10 led wip, dbg io chg , more notes
2026-01-10 led control debug done
2026-01-12 Mot Rx ok trace debug not working
    [main.c]
2026-01-12 faiel to get itm trace , using tx or edk usart for debug motor
2026-01-17 test debg use of tim1 for pwm light diming
2026-01-17 add kikack proh,sch,pcb and noye about it
    [edklight.kicad_pcb, edklight.kicad_sch]
2026-01-18 note mcu brd, sch/ lib with BlackPill and Mini F103
    [edklight.kicad_pcb, edklight.kicad_sch]
2026-01-18 fix pins in mini103 and bp103
    [edklight.kicad_pcb]
2026-01-24 pcb swicth to mini f103 updtae higo ,single pad for wire conection
    [edklight.kicad_pcb, edklight.kicad_sch]
2026-01-25 md udpate higo8 and brake addition , try chn pwm
    use of timer chn may help moving light to different mcu pin that would
    help pcb routin or proto wiring (no crossing shorter wire)
    [edklight.kicad_pcb, edklight.kicad_sch]
2026-01-26 add button connector info
2026-01-27 pcb : chg button pin add debounce capacitor
    [edklight.kicad_pcb, edklight.kicad_sch]
2026-01-27 try capacitor value for debounce on exti with inetrnall pull
2026-01-28 pcb : hi side mos wrong siden , chg few R+D footprint
    [edklight.kicad_pcb, edklight.kicad_sch]
2026-02-04 update doc with wired connector
2026-02-04 pcb change some placement inline with proto + wire con
    [edklight.kicad_pcb, edklight.kicad_sch]
2026-02-05 regen new i/o pin , brake a0 swap not 5V , new usb uart and usart swap
    [edklight.kicad_pcb, edklight.kicad_sch]
2026-02-05 regen uart irq enable missing, switch ld to c8 , usb uart cmd wip
    [edklight.kicad_sch]
2026-02-06 doc rear higo wiring/pinout
2026-02-06 wip usb uartx cmd and log
2026-02-08 refactor task name, erase cmd, brake on non move , light but rework
    [main.c, main.h]
2026-02-13 missing new file for button
2026-02-13 extract flight lvl fn, handle ch1 ch2n swap alternative , start powmn
    [main.c]
2026-02-13 tune short press time, fix long press , setup cong chg validated
    [main.c]
2026-02-13 on/off by button long press , high/low beam by short button
    [main.c, main.h]
2026-02-14 issue in brake debounce logic state not stored
    [main.c]
2026-02-14 regen pull up on brake minimize random on if float when motor off
2026-02-14 brake oberhide when steady logic wrong missing time reset when release
    [main.c]
2026-02-14 ev but long was generated for normal case
2026-02-14 finished proto pcb image top/down

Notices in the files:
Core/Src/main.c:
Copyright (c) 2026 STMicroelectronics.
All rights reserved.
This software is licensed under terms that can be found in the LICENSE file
